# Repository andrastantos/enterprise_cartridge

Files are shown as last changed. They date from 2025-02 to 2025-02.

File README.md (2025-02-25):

A 512kB ROM cartridge design for the Enterprise computer
========================================================

This design can be used to add up to 512kB of ROM to the cartridge port of the Enterprise computers. Since the port
only exposes 16 address pins, 8 pages are selectable using jumpers.

You can read up on whole project in detail here: https://www.modularcircuits.com/blog/2025/02/25/enterprise-128-a-blast-from-the-past/

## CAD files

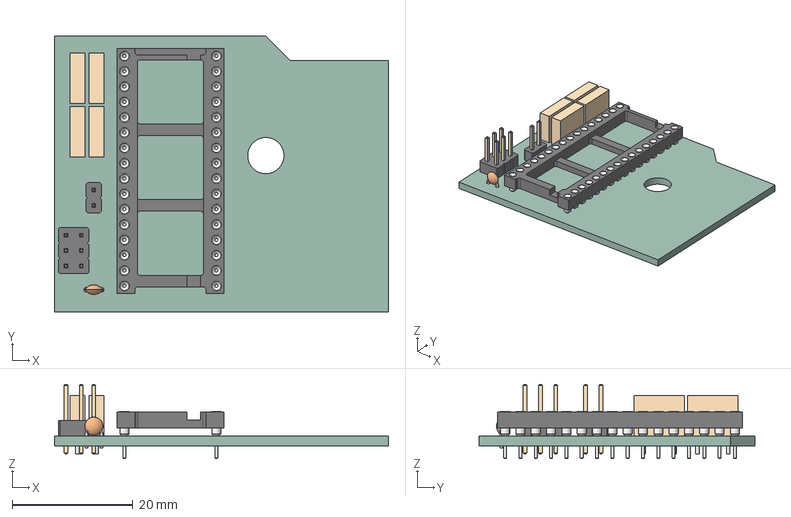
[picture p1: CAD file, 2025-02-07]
flash_board.step
55.4 x 45.7 x 12.3 mm
PinHeader_1x02_P254mm_Vertical
PinHeader_2x03_P254mm_Vertical
R_Box_L84mm_W25mm_P508mm x 4
C_Disc_D30mm_W16mm_P250mm
DIP_32_W1524mm_Socket
_autosave-flash_board_PCB

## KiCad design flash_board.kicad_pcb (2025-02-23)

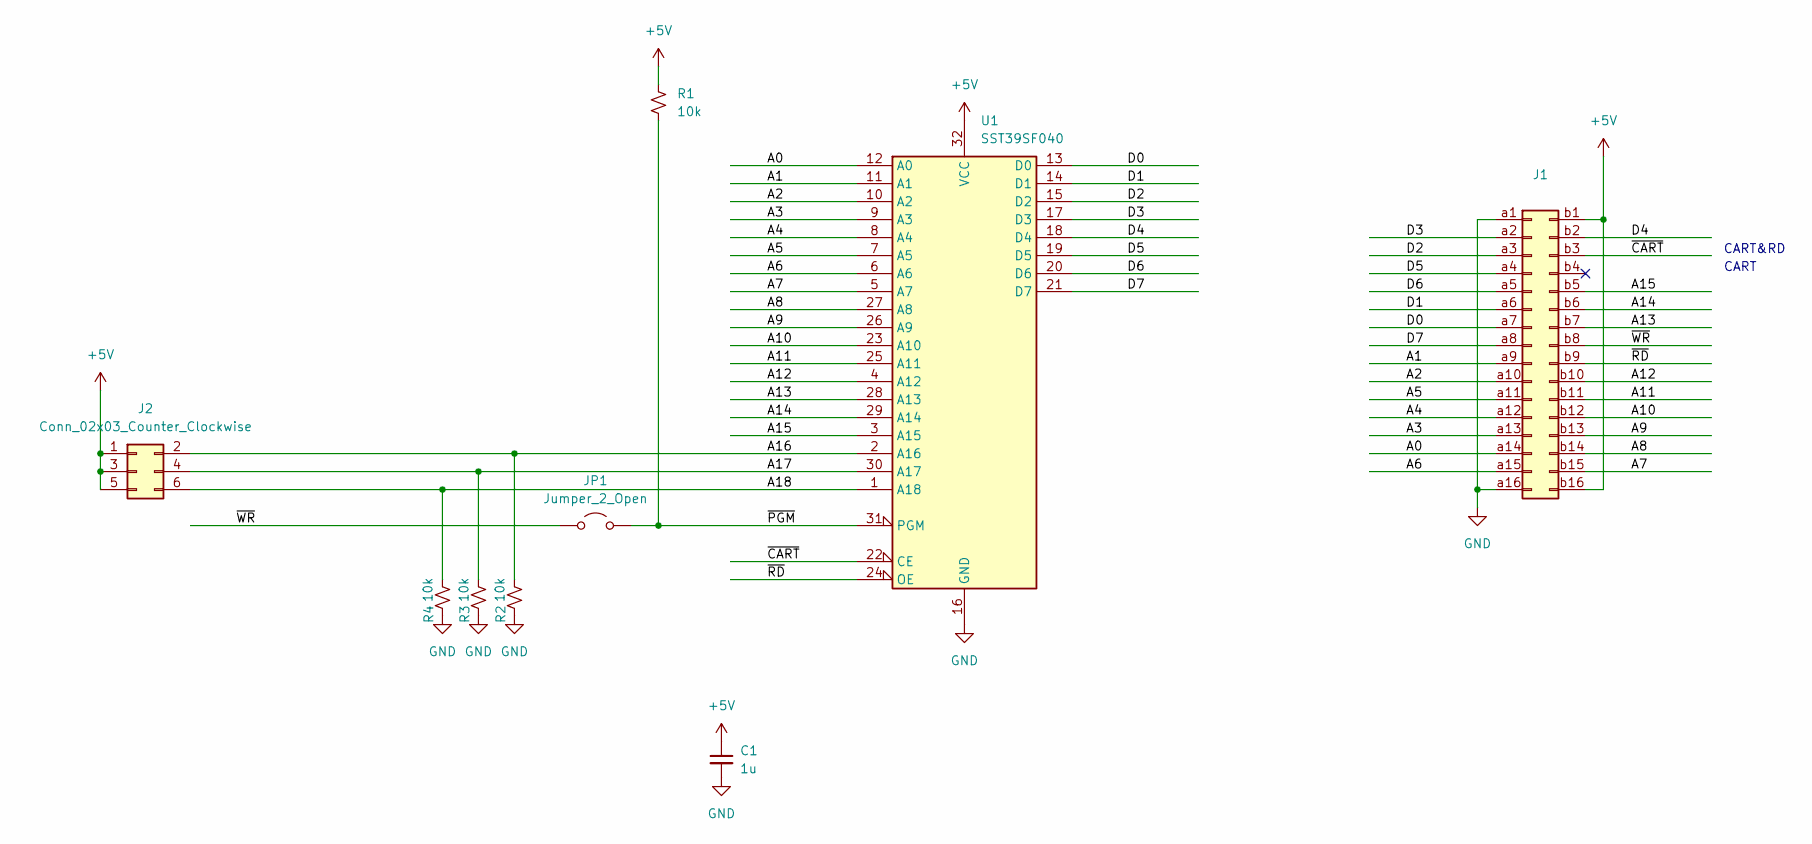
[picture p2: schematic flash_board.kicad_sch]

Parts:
C1: 1u; C_Disc_D3.0mm_W1.6mm_P2.50mm
J1: Conn_02x16_Row_Letter_First; ENTERPRISE_CARTRIGE_CONN
J2: Conn_02x03_Counter_Clockwise; PinHeader_2x03_P2.54mm_Vertical
JP1: Jumper_2_Open; PinHeader_1x02_P2.54mm_Vertical
R1, R2, R3, R4: 10k; R_Box_L8.4mm_W2.5mm_P5.08mm
U1: SST39SF040; DIP-32_W15.24mm_Socket_LongPads

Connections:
+5V: C1.1, J1.b1, J1.b16, J2.1, J2.3, J2.5, R1.1, U1.32 (VCC)
/A0: J1.a14, U1.12 (A0)
/A1: J1.a9, U1.11 (A1)
/A2: J1.a10, U1.10 (A2)
/A3: J1.a13, U1.9 (A3)
/A4: J1.a12, U1.8 (A4)
/A5: J1.a11, U1.7 (A5)
/A6: J1.a15, U1.6 (A6)
/A7: J1.b15, U1.5 (A7)
/A8: J1.b14, U1.27 (A8)
/A9: J1.b13, U1.26 (A9)
/A10: J1.b12, U1.23 (A10)
/A11: J1.b11, U1.25 (A11)
/A12: J1.b10, U1.4 (A12)
/A13: J1.b7, U1.28 (A13)
/A14: J1.b6, U1.29 (A14)
/A15: J1.b5, U1.3 (A15)
/A16: J2.2, R2.1, U1.2 (A16)
/A17: J2.4, R3.1, U1.30 (A17)
/A18: J2.6, R4.1, U1.1 (A18)
/D0: J1.a7, U1.13 (D0)
/D1: J1.a6, U1.14 (D1)
/D2: J1.a3, U1.15 (D2)
/D3: J1.a2, U1.17 (D3)
/D4: J1.b2, U1.18 (D4)
/D5: J1.a4, U1.19 (D5)
/D6: J1.a5, U1.20 (D6)
/D7: J1.a8, U1.21 (D7)
/~CART: J1.b3, U1.22 (CE)
/~PGM: JP1.2 (B), R1.2, U1.31 (PGM)
/~RD: J1.b9, U1.24 (OE)
/~WR: J1.b8, JP1.1 (A)
GND: C1.2, J1.a1, J1.a16, R2.2, R3.2, R4.2, U1.16 (GND)

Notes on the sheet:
CART
CART&RD

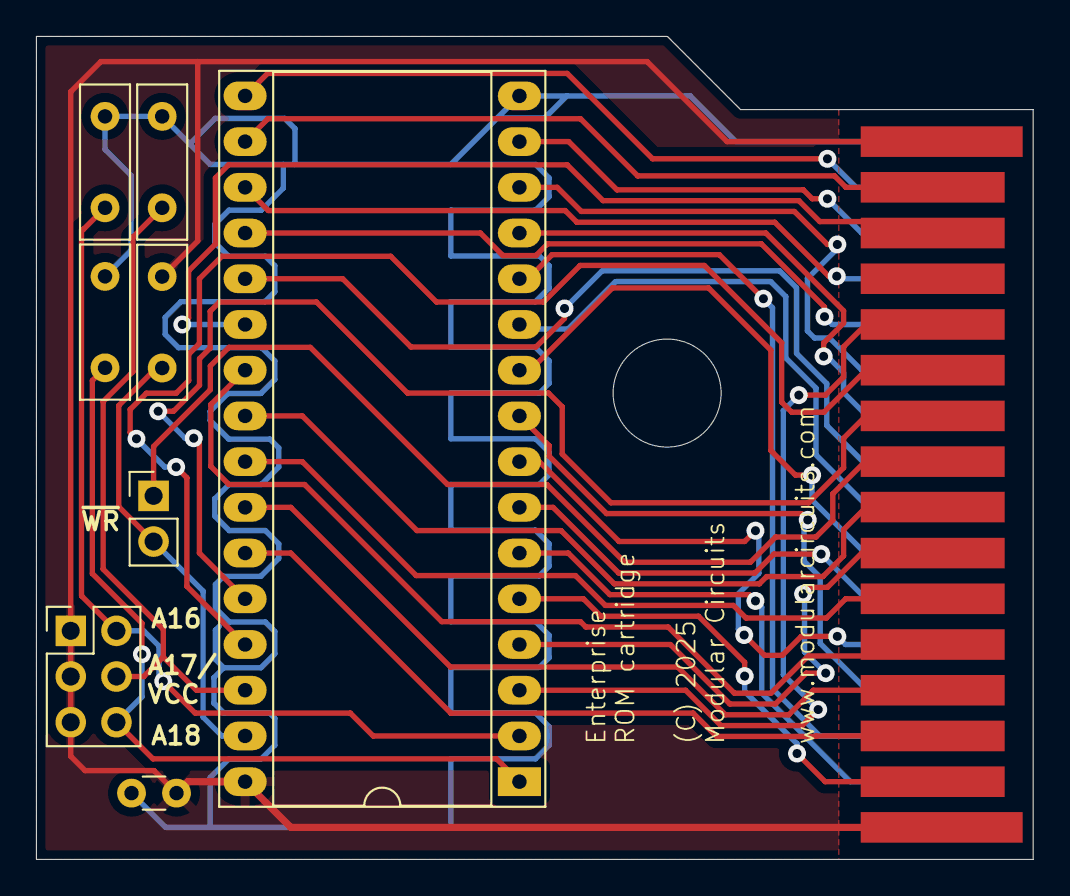
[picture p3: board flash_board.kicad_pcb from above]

Board: 2 copper layers, 55.4 x 45.7 mm, 9 parts (0 on the bottom side), 33 nets.

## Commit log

2025-02-03 Updated board to hopefully final shape
    [flash_board.kicad_pcb]
2025-02-06 Resized board to stay flush with case
    [flash_board.kicad_pcb]
2025-02-06 Some small fixes and release package.
    [flash_board-B_Cu.gbr, flash_board-B_Mask.gbr, flash_board-Edge_Cuts.gbr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]
2025-02-07 Changed hole size to match 3D printed case model.
    [flash_board-B_Cu.gbr, flash_board-B_Mask.gbr, flash_board-Edge_Cuts.gbr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]
2025-02-23 Fixed D5 location on connector.
    [flash_board.kicad_pcb, flash_board.kicad_sch]

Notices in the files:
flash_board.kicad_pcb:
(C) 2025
